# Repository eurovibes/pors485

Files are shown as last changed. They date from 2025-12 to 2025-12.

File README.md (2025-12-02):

<!-- SPDX-FileCopyrightText: 2025 Benedikt Spranger <b.spranger@linutronix.de> -->
<!-- SPDX-License-Identifier: CERN-OHL-S-2.0 -->




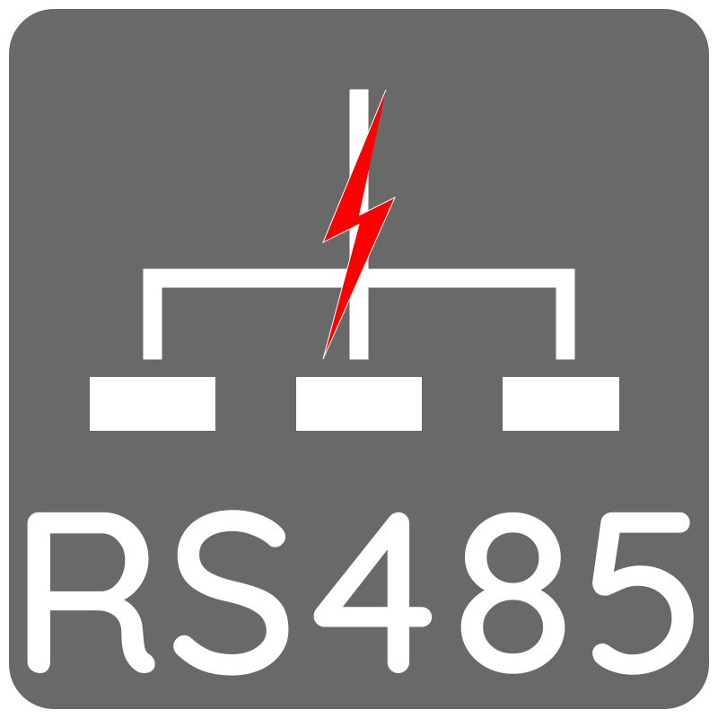
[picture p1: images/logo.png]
pors485 logo


# pors485 - A Power over RS485 board

To pass electric power along with data on shared line is a common requirement.
The Power over RS485 board provides a solution to fit these needs. The board
can both inject and receive power from the bus. It is designed to operate with
Voltages from 7V to 36V up to a current of 4A.

## License rules

pors485 is provided under the terms of the CERN-OHL-S license version 2 as
provided in the LICENSES/CERN-OHL-S-2.0 file.

Instead of adding license boilerplates to the individual files, pors485 uses
SPDX license identifiers, which are machine parseable and considered legaly
equivalent.

The SPDX license identifier in pors485 shall be added at the first possible
line in a file which can contain a comment. This is normally the first line
except for scripts. Scripts require the #!PATH_TO_INTERPRETER tag in the
first line; place the SPDX identifier into the second line.

The SPDX license identifier is added in form of a comment.

## Copyright and License

Copyright Benedikt Spranger 2021.
This source describes Open Hardware and is licensed under the CERNOHL-S v2.
You may redistribute and modify this source and make products using it
under the terms of the CERN-OHL-S v2
(https://ohwr.org/cern ohl s v2.txt ).
This source is distributed WITHOUT ANY EXPRESS OR IMPLIED
WARRANTY, INCLUDING OF MERCHANTABILITY, SATISFACTORY
QUALITY AND FITNESS FOR A PARTICULAR PURPOSE. Please see
the CERN-OHL-S v2 for applicable conditions.
Source location: https://github.com/eurovibes/pors485
As per CERN-OHL-S v2 section 4, should You produce hardware based
on this source, You must where practicable maintain the Source Location
visible on the external case of the pors485 or other products you make using
this source.

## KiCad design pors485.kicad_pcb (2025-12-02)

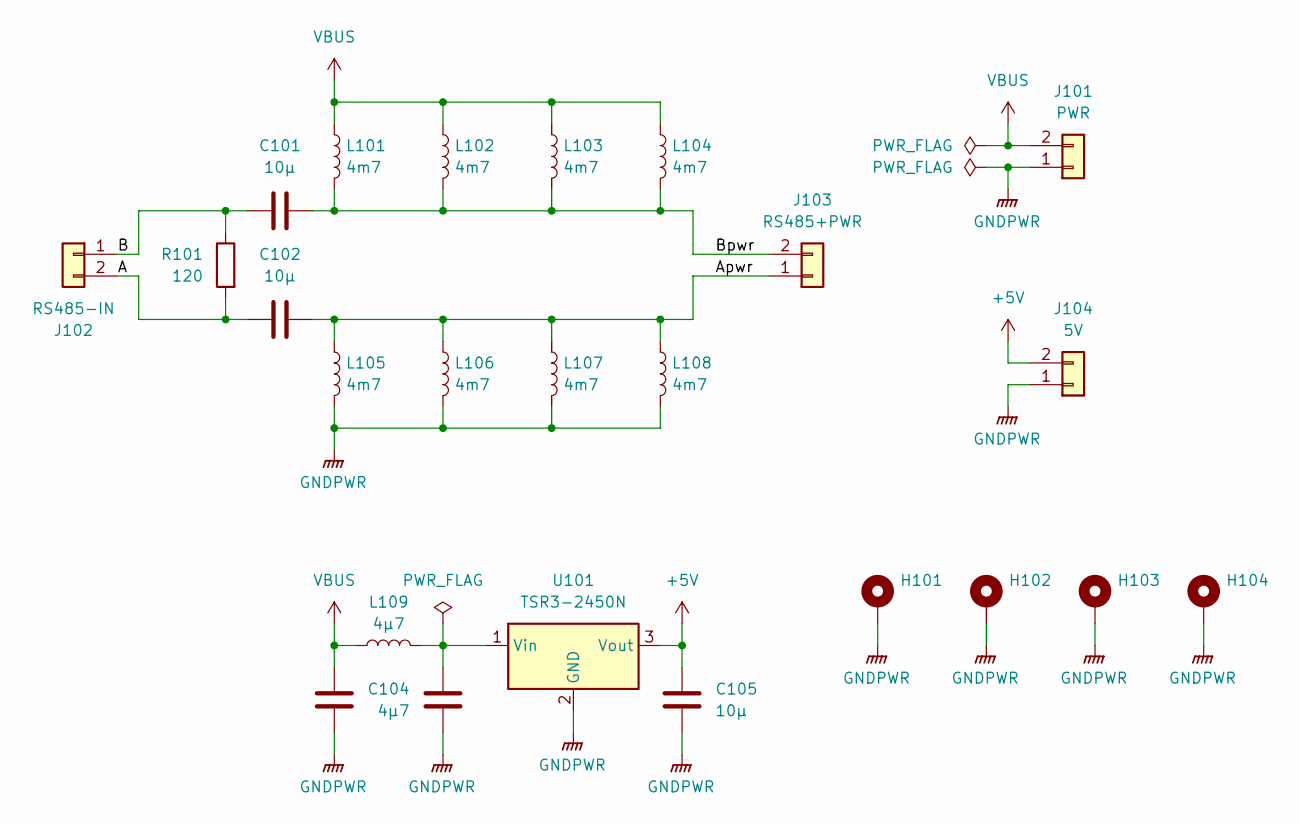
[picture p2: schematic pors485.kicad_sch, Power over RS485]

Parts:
C101, C102, C105: 10µ; C_0805_2012Metric; lcsc# C440198
C103, C104: 4µ7; C_1206_3216Metric; lcsc# C29823
H101, H102, H103, H104: MountingHole_3.2mm_M3_ISO14580_Pad
J101: PWR; TerminalBlock_WAGO_236-402_1x02_P5.00mm_45Degree
J102: RS485-IN; TerminalBlock_WAGO_236-402_1x02_P5.00mm_45Degree
J103: RS485+PWR; TerminalBlock_WAGO_236-402_1x02_P5.00mm_45Degree
J104: 5V; TerminalBlock_WAGO_236-402_1x02_P5.00mm_45Degree
L101, L102, L103, L104, L105, L106, L107, L108: 4m7; L_15x15mm_H8mm; lcsc# C970556
L109: 4µ7; L_Changjiang_FXL0530; lcsc# C177246
R101: 120; R_1206_3216Metric; lcsc# C17909
U101: TSR3-2450N; Converter_DCDC_TRACO_TSR2-24xxN_TSR2-24xxxN_THT

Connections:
+5V: C105.2, J104.2, U101.3 (Vout)
/A: C102.1, J102.2, R101.2
/Apwr: C102.2, J103.1, L105.1, L106.1, L107.1, L108.1
/B: C101.1, J102.1, R101.1
/Bpwr: C101.2, J103.2, L101.2, L102.2, L103.2, L104.2
GNDPWR: C103.2, C104.2, C105.1, H101.1, H102.1, H103.1, H104.1, J101.1, J104.1, L105.2, L106.2, L107.2, L108.2, U101.2 (GND)
unnamed: C104.1, L109.2, U101.1 (Vin)
VBUS: C103.1, J101.2, L101.1, L102.1, L103.1, L104.1, L109.1

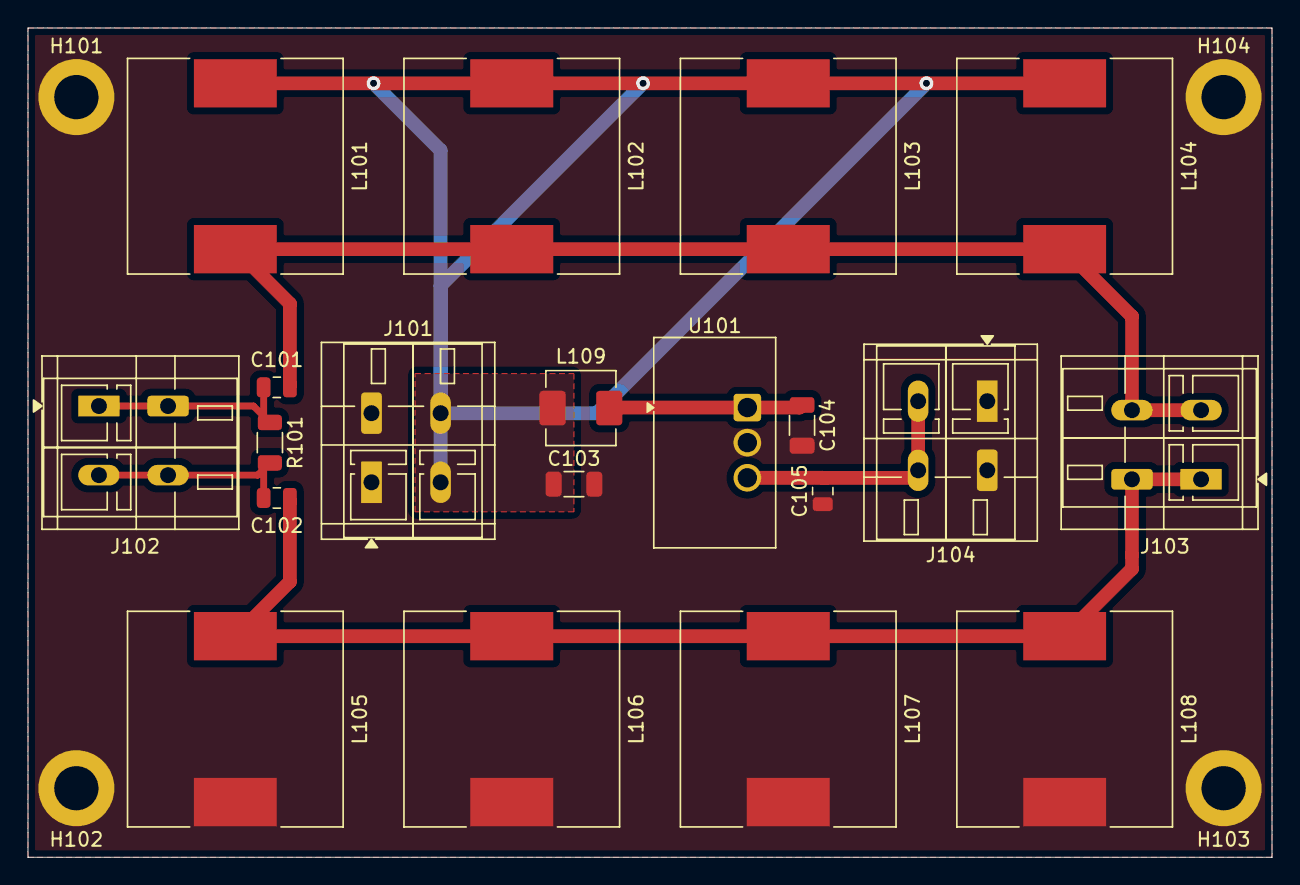
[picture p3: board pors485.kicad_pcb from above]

Board: 2 copper layers, 90.0 x 60.0 mm, 24 parts (0 on the bottom side), 8 nets.

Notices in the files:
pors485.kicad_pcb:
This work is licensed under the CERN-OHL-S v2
